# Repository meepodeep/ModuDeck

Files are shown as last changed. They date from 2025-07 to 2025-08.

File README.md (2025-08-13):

# ModuDeck

https://youtu.be/RfgZwogNPUY





## A modular cyberdeck that supports multiple SBCS.
  - ### Modules
    - [Exoskeleton](##exoskeleton)
    -   [Compute Modules](##compute) 
        - [Pi 5](###pi-5)
        - [Pi zero 2 w](###pi-zero-2-w)
        - [Lattepanda Mu](###lattepanda-mu)
    - [Battery Modules](##battery)
      - [High Capacity](###2p4s)
      - [Low Capacity](###4s1p)
    - [Keyboard](##keyboard)
    - [Display](##display)
    - [How to assemble modules](##final-assembly)
  - [BOM](#bom) 
## What is the point
I set out to make a modular cyberdeck because I wanted to try to design something that doesnt follow the modern design trends of slimmer and less upgradeable and repairable computers. The modular concept helps alleviate these problems by making use of easily replaceable and upgradeable batteries and SBCs. This also solves the problem of many custom projects being very inconvenient to do maintenance on. For example, some people hotglue everything into place, making the project nearly impossible to work on. In this project, however, every part that you would need to replace is easily replaceable with m3 and m2.5 hardware, securing it in place. 

# Assembly Instructions
- ## Exoskeleton
  - ### Printing
1. Print Both main case peices vertically
2. Print both rear cases flat or vertically if you have elephants foot issues
3. Assemble both sides of each part together using either superglue, plastic welding, or your preferred method of attaching 3d prints.
4. Use m3 hardware to secure the back on once done with wiring exept leave these 3 holes unscrewed, they are for mounting the modules.
5. 
6. 

  - ### Wiring
1. Press fit all of the connectors including, HDMI, XT60, and the magnetic 4pin magnetic connector and glue them in once you know it will meet on the other end.
   
   
   
   
  
3. Solder the 12v supply for the xt60 on the battery to the 12v supply on the compute xt60 with 18awg wire.
4. Solder the 5v supply for the xt60 on the battery to the 5v supply on the compute xt60 with 18awg wire.
   
   
   
   
- ## Compute
  - ### Pi 5
 
  
  
1. Print the pi 5 compute model.
2. Assemble the cooler.
3. Solder 28awg wire to the 4 USB pins from the Bottom of the USB 2.0 connector on the set of pins closest to the edge of the board.
4. Remove the casing from the micro HDMI to HDMI adapter.
5. Press the HDMI into the casing and plug it into the pi 5 and use double sided tape or hot glue to secure the big side.
6. Solder the 5v and gnd connections from the gpio to the + and - terminals onto an xt60 connector using 18awg wire. Press the connector into the 5v part of the module.

  Raspberry-Pi-5-Pinout--1
  
7. Press the 5v Xt60 into the case and glue it in with ca.
8. Solder the other ends of the wires coming from the USB to the magnetic connector in this order, from left to right, on the pin side. Ground, Data+, Data-, Vcc.
9. Press the Magnetic connector into the case and use ca to secure it after removing the plastic side holes.
10. Screw the pi into the mounting posts with m2.5 hardware.
  - ### Pi zero 2 w



1. Print the Pi Zero Compute model.
2. Assemble the cooler
3. Decase the USB hub.
4. Solder 28awg wire to the pins of the USB port at the end of the hub.
5. Solder the other ends of the wires coming from the USB to the magnetic connector in this order, from left to right, on the pin side. Ground, Data+, Data-, Vcc.
6. Press the Magnetic connector into the case and use ca to secure it after removing the plastic side holes.
7. Solder the 5V and GND connections from the GPIO to the + and - terminals onto an xt60 connector using 18awg wire.
8. Press the connector into the 5V part of the module.

j8header-zero

9. Decase the mini HDMI adapter on the big HDMI side.
10. Press the HDMI into the case, and plug in the mini HDMI.
11. Screw the pi into the mounting posts with m2.5 hardware.
  - ### Lattepanda mu
1. Print the Lattepanda compute module.
2. Assemble the Panda, cooler, and devboard.
3. Solder 28awg wire to the 4 USB pins on the bottom of the furthest USB connector from the edge of the board on the port that is covered by the case.



4. Solder 18awg wire to the + and - of the barrel jack and solder them to the + and - of an xt60.
5. Press that into the 12V supply port on the module.
6. Solder the other ends of the wires coming from the USB to the magnetic connector in this order, from left to right, on the pin side. Ground, Data+, Data-, Vcc.
7. Use the hdmi male to female connector and decase the in end enough so it is flush with the outside of the case when you insert it.
8. Use double sided tape or any mounting method to secure it into place
9. plug in the hdmi
10. Insert the magnetic connector into its port and use ca to secure it after removing the plastic side holes

- ## Battery
  - ### Build
1. Print battery module cover.
2. Print battery module.
  - ### 2p4s deprecated!!! DOES NOT FIT MAKE 4s1p unless you are going to do a case redesign which i would very much appreciate!
    - Wiring
- # BEFORE DOING THIS MAKE SURE ALL OF THE CELLS ARE AT THE SAME VOLTAGE SO YOU DONT EXPLODE YOU HOUSE!!
1.  Wire 4 pairs of cells in a 1p configuration by spot welding nickel strips in between the cells.
2.  
3.  Wire all 4 of those 1p cells in series into a 2p4s Configuration by spot welding nickel strips, this is the green section of the diagram.
4.  Solder the 5 wires coming from the JST pins of the the BMS and to the parts of the battery; these are the purple wires in the diagram.
5. 
6.  Solder a 12awg wire to the - terminal on the BMS.
7.  Solder a 12awg wire to the + terminal on the BMS and to the power switch, solder another 12awg wire to the other side of said switch, and press it into the case.
8.  
9.  Follow the wiring diagram from step 8 in order to complete the battery, then make sure to insulate all of the connections with your preferred method(I used kapton tape).
10.  Press both XT60s into their respective ports.
11.  Screw on the top using m3 hardware.
  - ### 4s1p
    - Same as 2p4s, but instead of having cell pairs, just use individual cells. 
- ## Keyboard
- 

1. Pop every switch into the plate 
2. Solder all of the switches onto the PCB.
3. Solder all of the diodes onto the PCB in the same direction.
4. Solder the Pi Pico onto the top of the PCB upside down.
5. Use the qmk cli app to flash the provided keyboard firmware file in the repo by putting the file in your keyboards folder and running qmk flash -kb modudeck -km default with the pi pico in bootloader mode plugged into the PC (you gotta be on linux or mac for this).
6. Plug in the micro usb breakout board
7. Solder a 28awg wire onto each of the usb pads.
8. Solder the other ends of the wires coming from the USB to the magnetic connector in this order, from left to right, on the pin side vcc, Data-, Data+, Ground.
9. Press the magnetic connector into its slot where the compute module clips in and ca glue it in.
10. 
11. Slide the keyboard in and screw it down using m3 hardware.
- ## Display
1. Print both screen mount halves and secure them together using ca plastic welding or your preferred adhesive.
2. Use double-sided tape to secure the driver board to the back of the screen on the left side, away from the compute module.
3. Position the screen in the main case and put the scren mount around it aligned with the screw holes.
4. Screw in m3 hardware from the top of the case in all of the holes.
5. Plug the HDMI coming from the compute module bay into the display board.
6. Use 18awg wire to the 12V XT60 from the battery module bay to the power pads on the driver board after desoldering the barrel plug.
7. (you need the barrel plug for the battery)
- ## Final Assembly
1. Slot the compute module into the left of the cyberdeck making sure all of the connectors line up.
2. Use 2 m3 bolts to secure the module in place.
3. 
4. Slot the battery in, turned off, into the slot on the right, making sure all of the connectors line up.
5. Screw in one m3 bolt to secure it in place
6. 

# BOM

| Item |	Quantity |	Total price+Shipping | Use In project	| Item Source
| --- | --- | --- | --- |--- |
| General |||||			
| Display |	x1 |	$64.19 |	displays | https://www.ebay.com/itm/145841358470? |
| m3 hardware kit |	x1	| $7.99|	Mount most things	| https://www.amazon.com/Hincell-540pcs-Button-Washers-Stainless/dp/B0D1CV8V9Y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|
|m2.5 4mm |	x1 |	$1.86 |	mount the pis if you use them |	https://www.aliexpress.us/item/3256805692588351.html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|
|18awg wire	| x1 |	$13.76 | most wiring |	https://www.amazon.com/Nilight-Electrical-Conductor-Extension-Amplifier/dp/B0CYZPW42Q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 |
|28awg wire	| x1 |	$7.99 |	Usb wiring |	https://www.amazon.com/Fermerry-Stranded-Silicone-Cables-Electrical/dp/B089CR4SDM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 |
|12awg wire |	x1 |	$3.94 |	Battery wires |	https://www.aliexpress.us/item/3256807129117447.html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|
|Filament	| x1 |	$20 |	be every printed part |	Idk wherever you get filament |
|xt60s	| x1 |	$8.99 |	be every printed part |	[amazon](https://www.amazon.com/Amass-Bullet-Connector-Upgrated-Sheath/dp/B074PN6N4K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) |
|Magnetic Connectors| x1 | $$3.67 | Connect usb |https://www.aliexpress.us/item/3256805098127227.html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|
|Nickel strip| x1| $5.69 | build batteries| https://www.amazon.com/MECCANIXITY-Nickel-Battery-Soldering-Welding/dp/B0CVXLLGCQ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|
|Total|| $138.08 |||
||||||
|Keyboard Parts	| | | | |	
|Pi pico |	x1 |	$4 |	drive the keyboard | https://www.adafruit.com/product/4864 |
|usb breakout| x1 |$10 | breakout pico usb | https://www.amazon.com/dp/B0DDSX113L?psc=1&smid=A13KOVEB7K7KUP&ref_=chk_typ_imgToDp|
|Keyboard pcb	| x5 |	$35.47 |	Be a keyboard PCB |	PCBWAY |
| diodes | x100 Buy the x100 pack | $2.99 | be diodes | https://keeb.io/products/1n4148-diodes?variant=42525667334 | 
|Gateron Red	| x100	| $34.40 |	Be switches |	https://www.aliexpress.us/item/3256805905674117 |
|Keycaps |	x80 |	$14.16 |	Be keycaps |	https://www.aliexpress.us/item/3256807292808339.html? |
|Shipping |	$6.99	| | | |
|Total | |$95 | | |		
||||||
|Battery Module 2p4s |||||				
|DC-DC converter |	x2 |	$25.60 |	Convert the battery voltage to 12v/5v |	https://www.dfrobot.com/product-2599.html |
|18650s | x8 |	$29.28 |	be batteries |	https://www.18650batterystore.com/products/samsung-25r-18650?variant=37119890063511 |
|Bms |	x1 |	$1.75 |	be a bms for the batteries |	[Amazon](https://www.amazon.com/dp/B07X28845M?psc=1&smid=A30QSGOJR8LMXA&ref_=chk_typ_imgToDp) |
|RA11131121 |	x1 |	$0.69 |	power switch |	https://www.mouser.com/ProductDetail/E-Switch/RA11131121?qs=QtyuwXswaQhes8SRTBHYHQ%3D%3D&mgh=1&gQT=1 |
|373 |	x1 |	$0.95 |	charger |	https://www.mouser.com/ProductDetail/Adafruit/373?qs=GURawfaeGuDDC%2FyE6Usrdw%3D%3D |
|Total| |	$58.27 | | |	
|Battery Module 4s1p |||||	
|DC-DC converter |	x2 |	$25.60 |	Convert the battery voltage to 12v/5v |	https://www.dfrobot.com/product-2599.html |
|18650s | 	x4 |	$18.59 |	be batteries |	https://www.18650batterystore.com/products/samsung-25r-18650?variant=37119890063511 |
|Bms |	x1 |	$1.75 |	be a bms for the batteries |	[Amazon](https://www.amazon.com/dp/B07X28845M?psc=1&smid=A30QSGOJR8LMXA&ref_=chk_typ_imgToDp) |
|RA11131121 |	x1 |	$3.26 |	power switch |	https://www.aliexpress.us/item/3256808591861621.html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 |
|Total | | $49.20 |	| |	
||||||
|Pi zero 2 w compute | | | | |
|pi zero 2 w	| x1 |	$23.00 |	Main computer |	https://www.adafruit.com/product/5291 |
|mini hdmi to hdmi adapter |	x1 |	$6.99 |	adapt the HDMI |	https://www.amazon.com/Micro-Adapter-Female-Support-Raspberry/dp/B09HS74STL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 |
| USB hub and pi cooloer	| x1 |	$9.99 |	Cool the pi and breakout usb |	https://www.amazon.com/Raspberry-iUniker-Aluminum-Passive-Adapter/dp/B09XK36QNB/140-2177712-4060064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 |
|Total |	| $39.98 |	| | |	
||||||	
|Pi 5 Compute | | | | |
|Pi 5 8gb |	x1 |	$96.98 |	main computer |	https://www.pishop.us/product/raspberry-pi-5-8gb/?searchid=0&search_query=pi+5|
|Micro HDMI to Standard HDMI |	x1 |	$4.25 |	hdmi adapter |	https://www.pishop.us/product/micro-hdmi-to-standard-hdmi-adapter-white/|
|Cooler	| x1 |	$8.95 |	cool the pi |	https://www.pishop.us/product/dedicated-all-in-one-aluminum-cooler-for-raspberry-pi-5-pwm/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|
|Total | | $110.18 | | |	
||||||
|Lattepanda Mu Compute| | | | |	
|Lattepanda Mu with lite carrier and active cooler |	x1 |	$220.00 |	main computer |	https://www.dfrobot.com/kit-004.html|
| male to female hdmi | x1 | $4.99 | hdmi out | https://www.amazon.com/VCE-Extension-Swivel-Adapter-Converter/dp/B07XD9JTMG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 |
|Total| |	$220.00| | |

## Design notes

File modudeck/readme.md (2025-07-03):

# modudeck

modudeck

*A short description of the keyboard/project*

* Keyboard Maintainer: [meepodeep](https://github.com/meepodeep)
* Hardware Supported: *The PCBs, controllers supported*
* Hardware Availability: *Links to where you can find this hardware*

Make example for this keyboard (after setting up your build environment):

    make modudeck:default

Flashing example for this keyboard:

    make modudeck:default:flash

See the [build environment setup](https://docs.qmk.fm/#/getting_started_build_tools) and the [make instructions](https://docs.qmk.fm/#/getting_started_make_guide) for more information. Brand new to QMK? Start with our [Complete Newbs Guide](https://docs.qmk.fm/#/newbs).

## Bootloader

Enter the bootloader in 3 ways:

* **Bootmagic reset**: Hold down the key at (0,0) in the matrix (usually the top left key or Escape) and plug in the keyboard
* **Physical reset button**: Briefly press the button on the back of the PCB - some may have pads you must short instead
* **Keycode in layout**: Press the key mapped to `QK_BOOT` if it is available

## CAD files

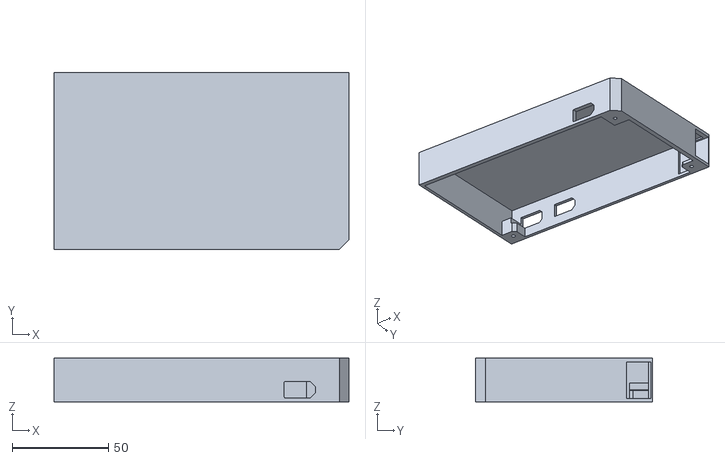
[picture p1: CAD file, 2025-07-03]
Final Print files/Battery/Battery module personal.stl
153.6 x 92.0 x 22.9

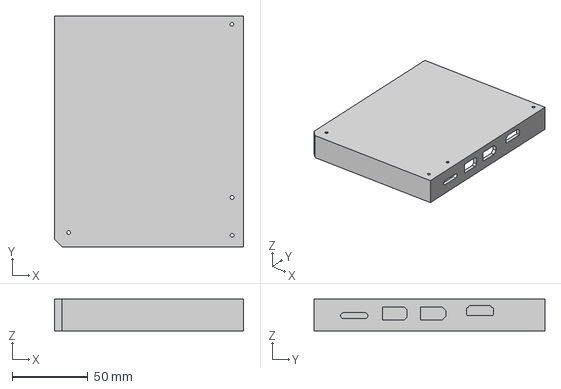
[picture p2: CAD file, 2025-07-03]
Final Print files/Compute Module Template.step
124.8 x 152.4 x 20.8 mm

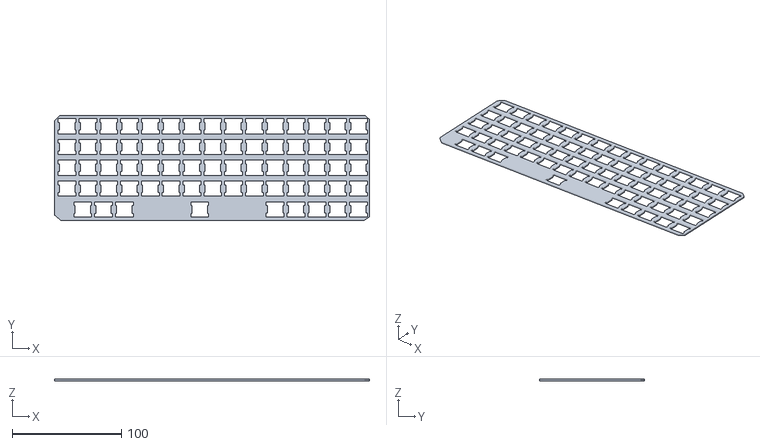
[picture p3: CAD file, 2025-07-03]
Final Print files/Exoskeleton/Plate.stl
288.4 x 95.8 x 1.60

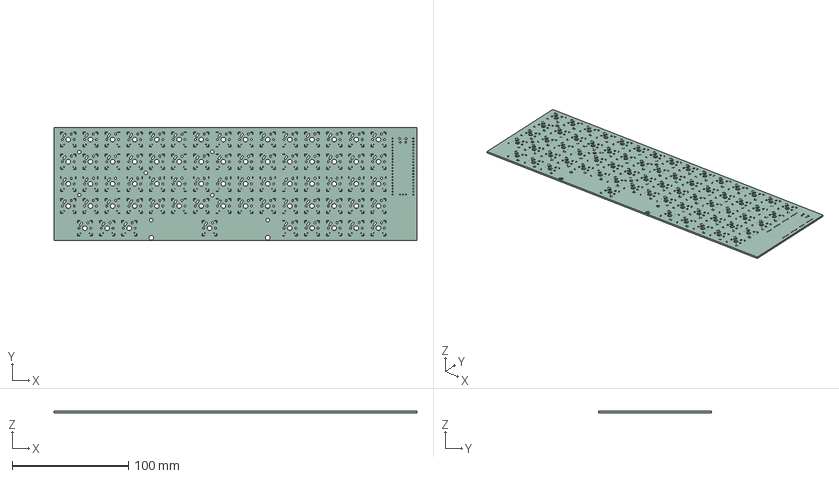
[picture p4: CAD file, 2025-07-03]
ModuDeck Keyboard/ModuDeck Keyboard.step
312.1 x 97.1 x 1.66 mm
OrangeDeck Keyboard_silkscreen
OrangeDeck Keyboard_PCB

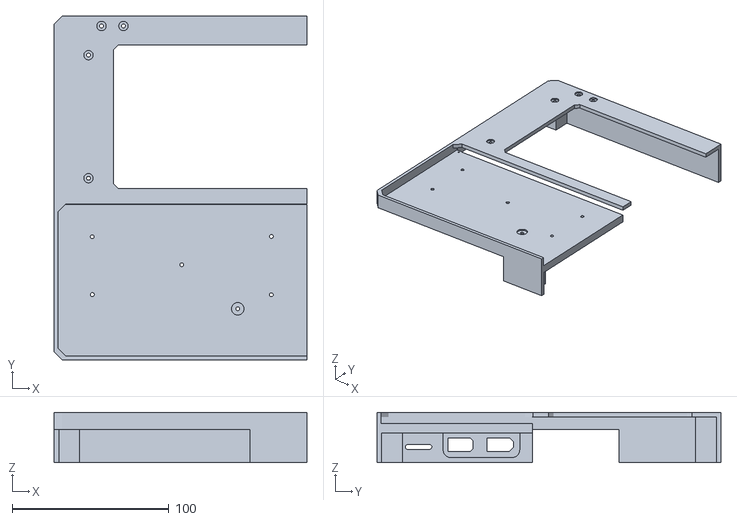
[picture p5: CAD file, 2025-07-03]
Final Print files/Exoskeleton/Case left.stl
161.3 x 219.6 x 32.0

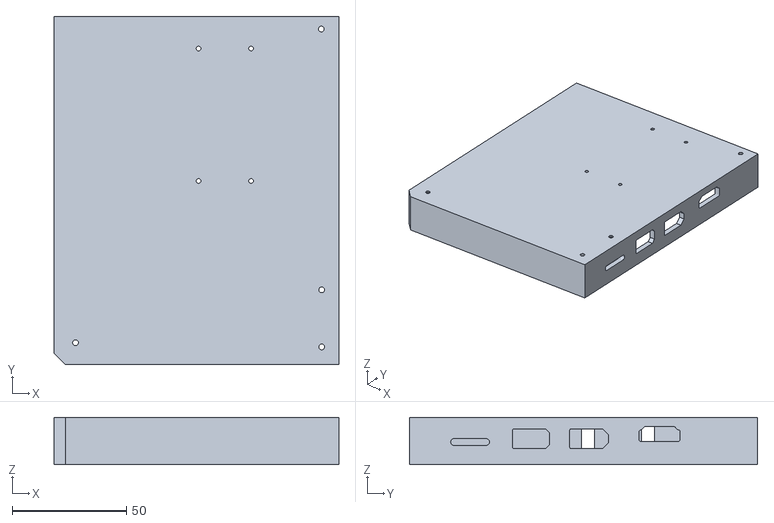
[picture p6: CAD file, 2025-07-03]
Final Print files/Exoskeleton/Rpi zero compute.stl
124.8 x 152.4 x 20.8

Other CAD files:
Final Print files/Lattepanda mu compute/Panda Compute.stl
Final Print files/Pi compute/Pi 5 Compute.stl
Final Print files/Compute template.stl

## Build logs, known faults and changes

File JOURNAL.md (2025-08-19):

---
title: "ModuDeck"
author: "Meepodeep"
description: "Cyberdeck but Modular!"
created_at: "2025-05-22"
---
# Total time spent ~109 hours, (I think I forgot to log a few days and I dont remember what days 😢)
# 5/22/25: Starting project

I started and finished the keyboard pcb design!





**Total time spent: 9h**
# 5/25/25: Worked on case.

Started making the case for the cyberdeck and also researched carrier board options. 



**Total time spent: 6h**

# 5/26/25: Worked on case.

Started designing mounts for the components in the case. 



**Total time spent: 2h**

# 5/27/25: Tried to make some sort of BOM.

I have been looking for parts for a while now. After making the Bom realized I'm going to have to sacrifice some features to stay in budget. I might try to integrate an old keyboard that I have instead of using the custom PCB I designed. Hopefully I can keep this thing under budget. 



**Total time spent: 4h**
# 5/28/25: Changed the concept entirely!

In order to stay under budget, I decided to make a modular system with you being able to hotswap SBC and battery modules in and out of the deck. I mostly just did a lot of CAD.



**Total time spent: 9h**
# 6/2/25: Finished some modules!

I finished the battery module, and i also finished the lattepanda mu module. I started work on the rpi zero module and i added some visual flairs.





**Total time spent: 3h**

# 6/3/25: Finished designing!

Today, I started doing alot of finalization steps. I made the pi 5 module, I also have a module template for both the battery and compute now. And I did alot of fine tuning of the mounts and printability of the design. After all of that, I went back and changed the keyboard to use a pi pico to make my life easier when soldering and setting up firmware. The most annoying part of today was just doing all the little touches to make this thing actually be reasonable for others and myself to assemble in real life like adding screw posts and splitting parts in half. 





**Total time spent: 7h**

# 6/4/25: started docs!

currently working on making instructions to build the project.

Check Readme.md for the progress

**Total time spent: 1h**

# 6/6/25: Worked on docs!

Wrote the assembly guide for the compute modules, batteries, and case. 

**Total time spent: 5h**

# 6/7/25: Worked on documentation and bom for every module 😢

Today I did a lot of writing. I wrote the assembly instructions for the remaining parts of the build, and i also wrote the bom with it being seperated to have individual costs for each module. 

**Total time spent: 5h**

# 6/11/25: edited some bits on the bom bc the prices changed. 

The display price changed due to going off sale, and I also ordered all the parts.

**Total time spent: 2h**

# 6/12/25: Edited the pi zero compute module

When I was test fitting something was off (i dont remember i forgot to log this day this is retroactive looking at commits) so I edited the 3d model.

**Total time spent 1h**

# 6/13/25: Edited ports.

Every port on the model was the wrong size, so nothing fit. I changed all of them to fit with measurements from the components that arrived today. Then I re printed and rebuilt it again. 

**Total time spent 5h**

# 6/14/2025 I HATE RASPBERRY PI OS!!!!

Ok so today I was just messing with linux to try to get a pi zero to do anything useful on the desktop. I have realized that this will be a command line machine until I can build a more useful compute module. I also started building stuff with the new HDMI slots and mounted the ports. 



**Total time spent 6h**

# 6/15/2025 I updated all the xt60 mounts to fit the connectors.

As the title says i edited the 3d model to fit the xt60s better.



**total time spent 2h**

# 6/24/2025 I built the battery module!

Today I worked on building the battery module, I finished all of the soldering, to then realize I ordered the wrong BMS. I ordered the BMS and I will replace the current one when it arrives! The voltage regulators do work, however, and that is cool. 





**Total time spent 10h**

# 6/26/2025 I made the keyboard and firmware!

Today I built the keyboard, designed a plate for it that I didnt realize I needed, and flashed it with my own custom qmk profile!



**Total timne spent 9h**

# 6/27/2025 Workerd more on the battery

Today I installed the new bms, to find out that I don't have the right charger to acctually charge the batteries. I also didn't realize that one of my connections came apart and spent multiple hours chasing that down. I need to redesign the case to accommodate an XT60 so I can plug it into my bench power supply. (also blew up a voltage regulator)

**Total time spent 10h**

# 6/28/25 Worked on the battery, again

Today I redesigned the case for the xt60 as mentioned previously, and transferred all of the parts from the previous case into the new one. Now everything works, but I can't charge while powered on, which is ok because the battery life is so good that it doesnt really matter.



**Total time spent 5h**

# 6/30/25 Worked on routing of cables and such.

Today I formally mounted the display driver board, and started work on the magnetic connectors for the keyboard USB, however the usb hub decided to blow up so im not doing that anymore. I now have to get a new one.



**Total time spent 4h**

# 7/2/2025 FINISHED IT

TODAY I AM DONE!!!! I soldered the keyboard magnet connectors, replaced the dead usb hub and made some final adjustments!

**Total time spent 4h**

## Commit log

2025-07-03 Final commit.... for now
    [Battery module personal.stl, Case left.stl, ModuDeck Keyboard.step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]
2025-07-03 final v2
    [Compute Module Template.step, Compute template.stl, ModuDeck v31.step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]
